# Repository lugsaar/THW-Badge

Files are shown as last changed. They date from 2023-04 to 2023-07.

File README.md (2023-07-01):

# THW-Badge

 [][cc-by-nc-sa]

## Images 

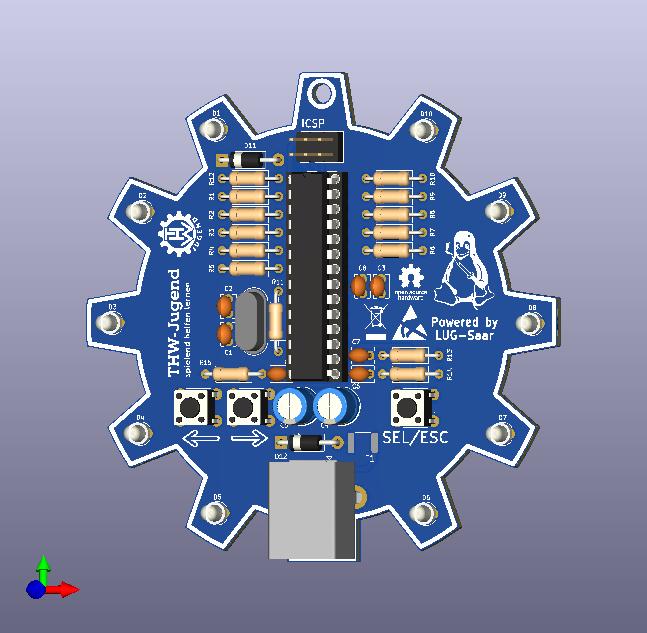
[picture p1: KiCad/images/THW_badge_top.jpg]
top

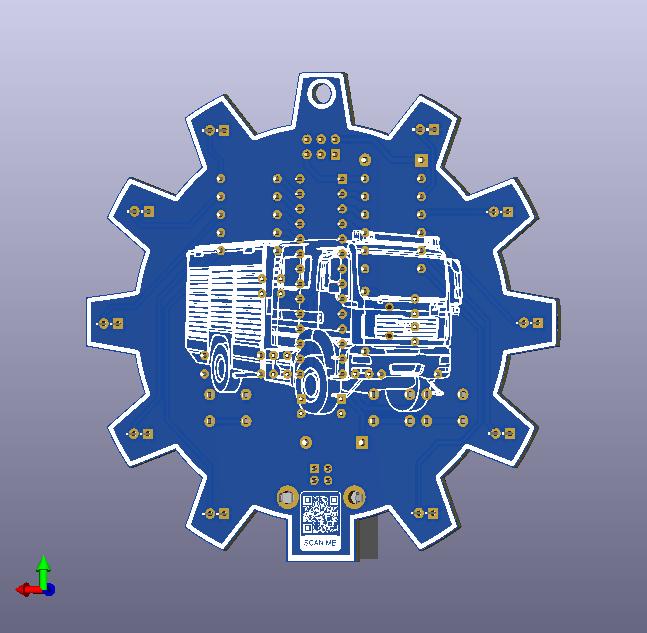
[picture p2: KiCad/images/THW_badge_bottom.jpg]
bottom

## License 

This work is licensed under a
[Creative Commons Attribution-NonCommercial-ShareAlike 4.0 International License][cc-by-nc-sa].

[][cc-by-nc-sa]

[cc-by-nc-sa]: http://creativecommons.org/licenses/by-nc-sa/4.0/
[cc-by-nc-sa-image]: https://licensebuttons.net/l/by-nc-sa/4.0/88x31.png
[cc-by-nc-sa-shield]: https://img.shields.io/badge/License-CC%20BY--NC--SA%204.0-lightgrey.svg

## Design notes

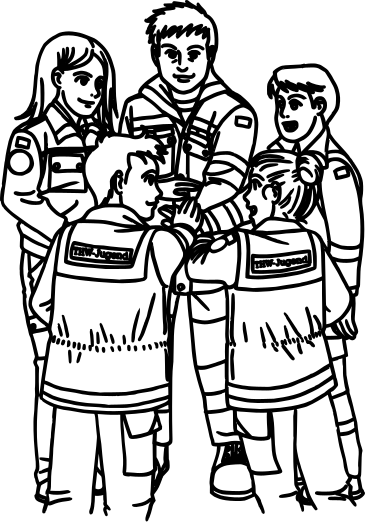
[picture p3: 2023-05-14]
KiCad/graphics/THW_Jugend_Personenkreis_Trace.jpg.png

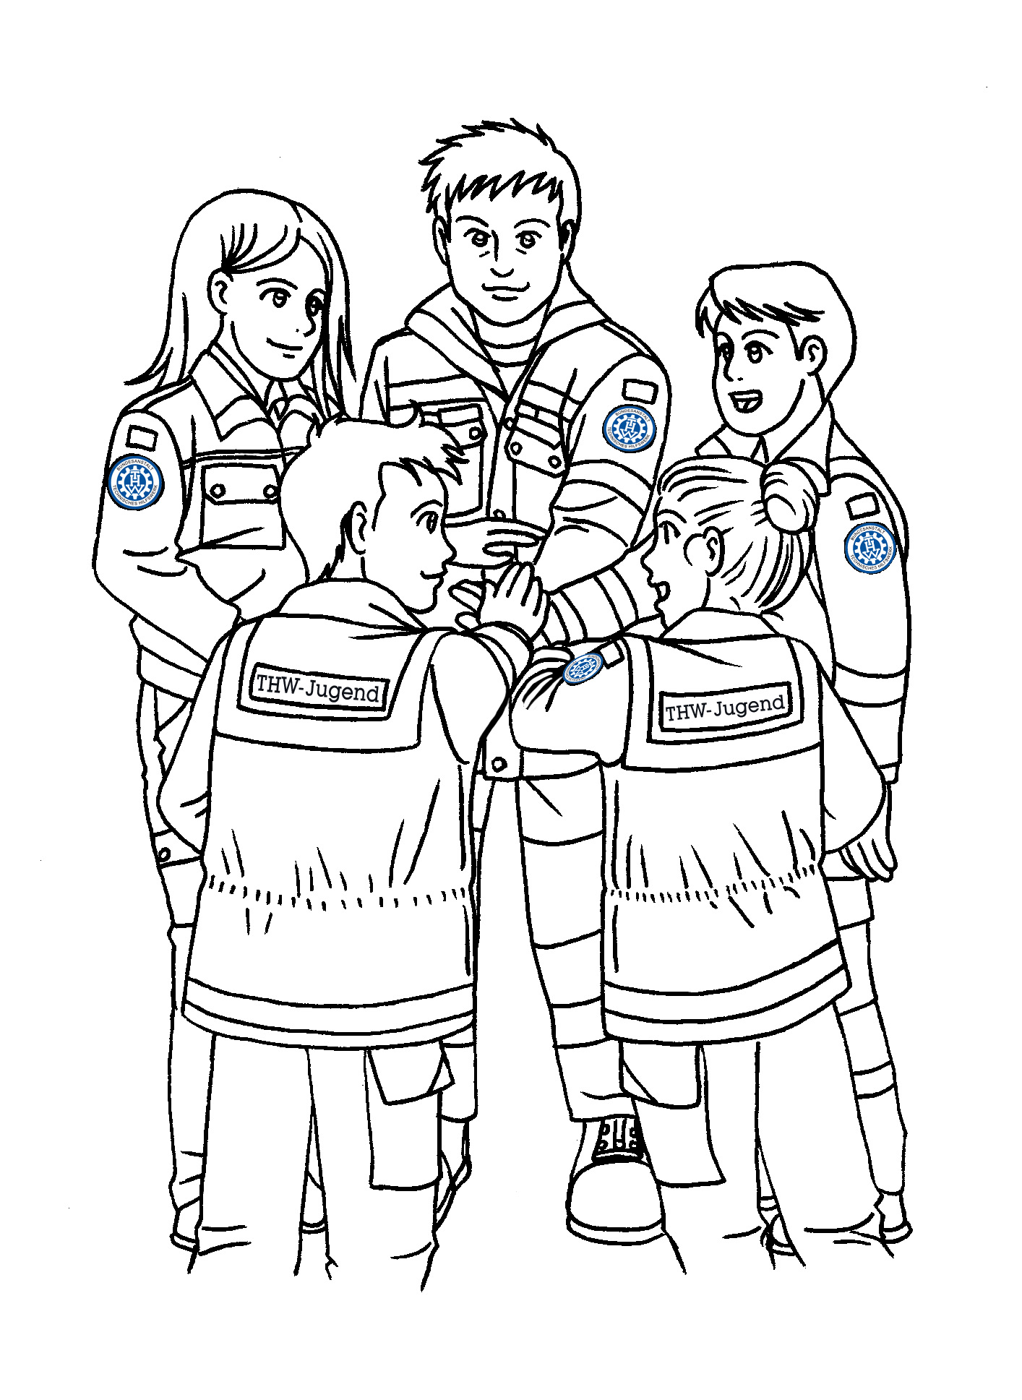
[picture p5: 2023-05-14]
KiCad/graphics/THW_Jugend_Personenkreis.jpg

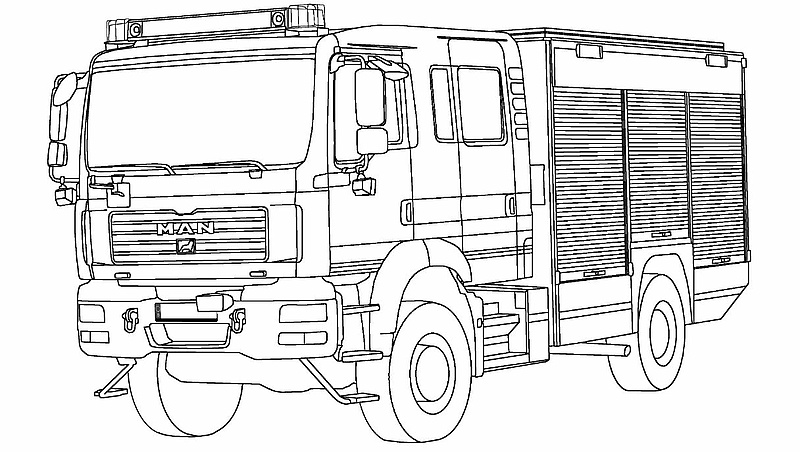
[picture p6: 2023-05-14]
KiCad/graphics/THW_GKW.jpg

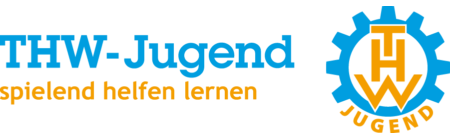
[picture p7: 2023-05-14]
KiCad/graphics/THW-Jugend_Schrift-lbox-450x140-trans.png

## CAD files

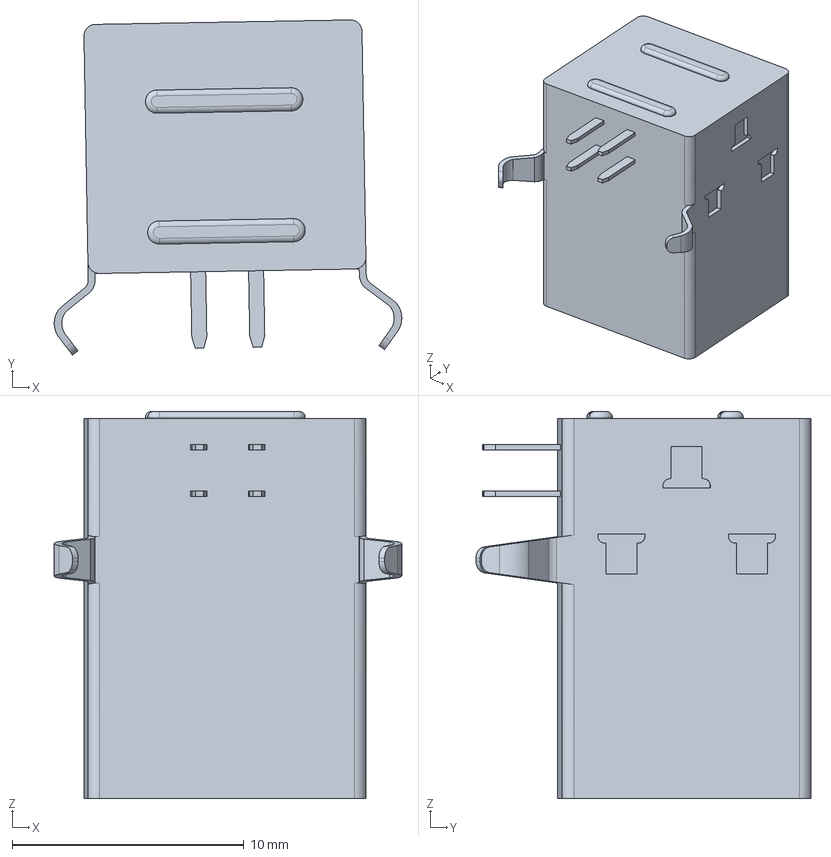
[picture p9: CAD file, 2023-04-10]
KiCad/3D_Models/USB_B_Lumberg_2411_02_Horizontal.stp
15.0 x 14.5 x 16.7 mm

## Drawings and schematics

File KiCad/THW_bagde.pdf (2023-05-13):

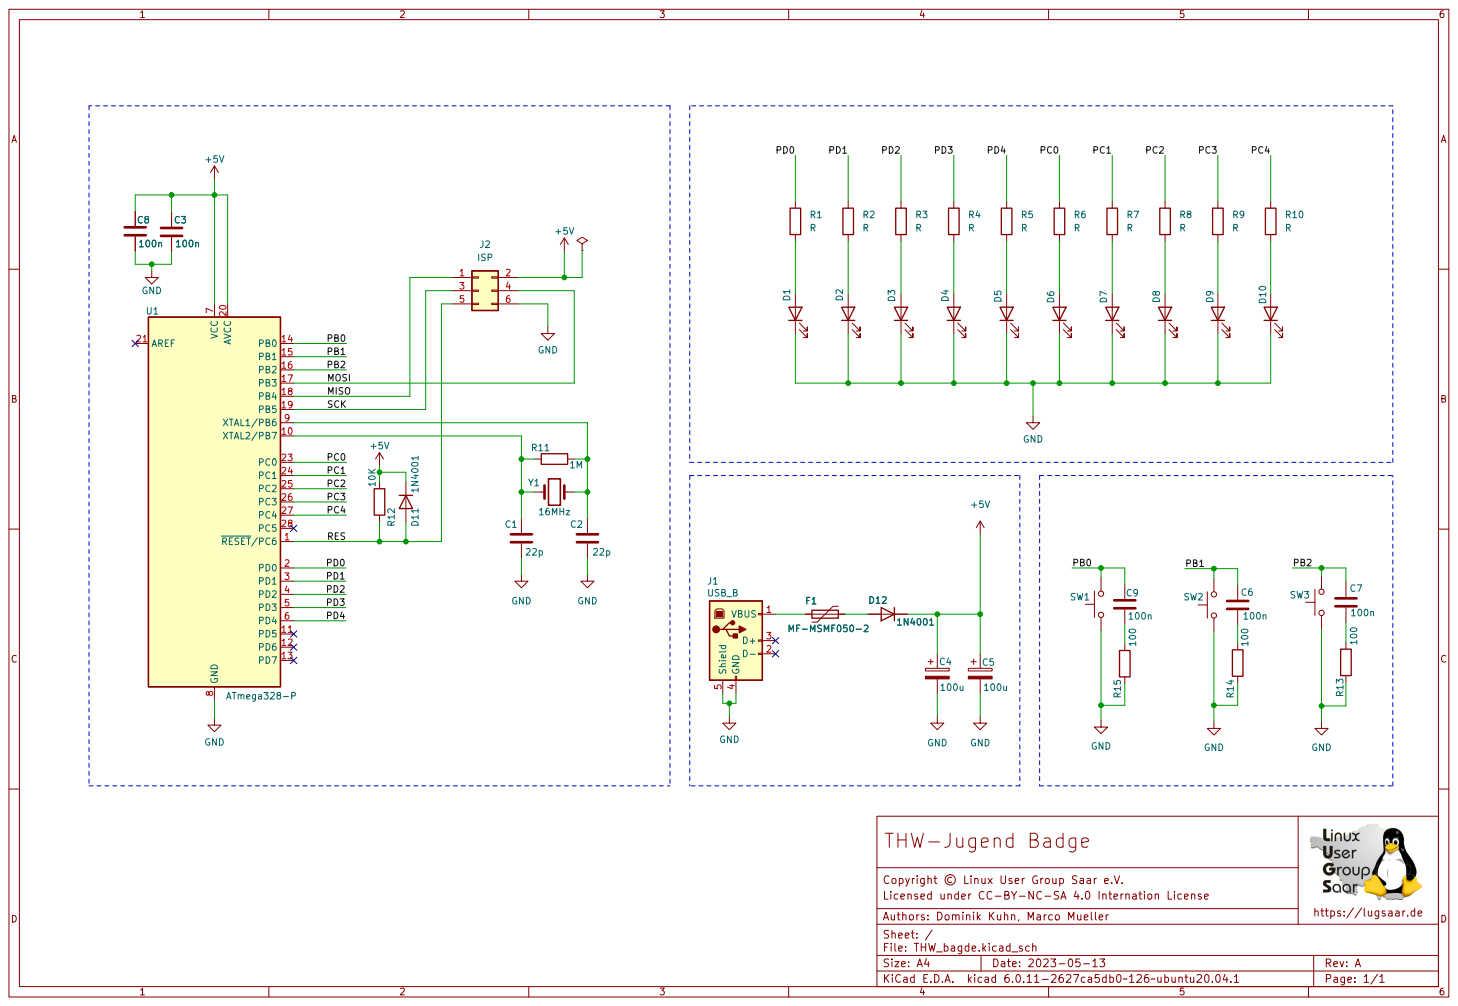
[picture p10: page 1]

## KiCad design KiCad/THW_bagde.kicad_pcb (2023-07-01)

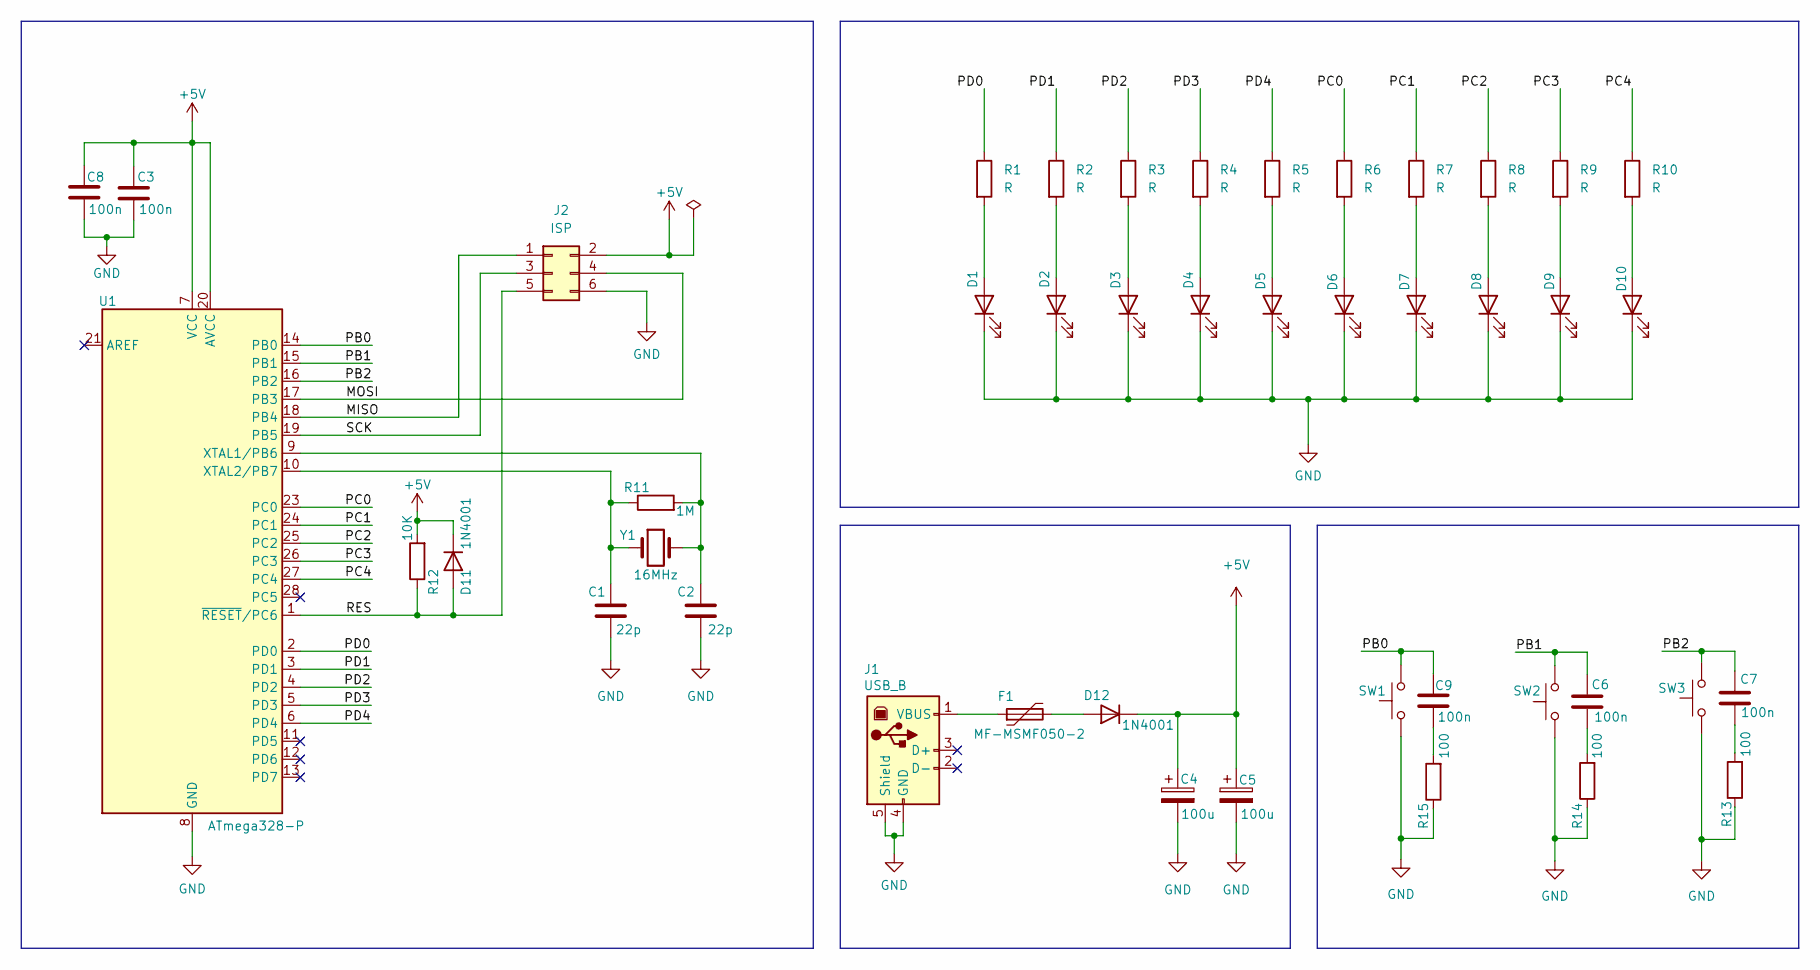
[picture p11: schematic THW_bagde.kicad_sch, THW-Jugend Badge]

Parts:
C1, C2: 22p; C_Disc_D3.8mm_W2.6mm_P2.50mm
C3, C6, C7, C8, C9: 100n; C_Disc_D3.8mm_W2.6mm_P2.50mm
C4, C5: 100u; CP_Radial_D6.3mm_P2.50mm
D1, D2, D3, D4, D5, D6, D7, D8, D9, D10: LED; LED_D3.0mm_Clear
D11, D12: 1N4001; D_DO-41_SOD81_P10.16mm_Horizontal
F1: MF-MSMF050-2; Fuse_1812_4532Metric
J1: USB_B; USB_B_Lumberg_2411_02_Horizontal
J2: ISP; PinHeader_2x03_P2.54mm_Vertical
R1, R2, R3, R4, R5, R6, R7, R8, R9, R10: R; R_Axial_DIN0207_L6.3mm_D2.5mm_P10.16mm_Horizontal
R11: 1M; R_Axial_DIN0207_L6.3mm_D2.5mm_P10.16mm_Horizontal
R12: 10K; R_Axial_DIN0207_L6.3mm_D2.5mm_P10.16mm_Horizontal
R13, R14, R15: 100; R_Axial_DIN0207_L6.3mm_D2.5mm_P10.16mm_Horizontal
SW1, SW2, SW3: SW_Push; SW_PUSH_6mm
U1: ATmega328-P; DIP-28_W7.62mm
Y1: 16MHz; Crystal_HC49-4H_Vertical

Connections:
+5V: C3.1, C4.1, C5.1, C8.1, D11.1 (K), D12.1 (K), J2.2, R12.2, U1.7 (VCC), U1.20 (AVCC)
/MISO: J2.1, U1.18 (PB4)
/MOSI: J2.4, U1.17 (PB3)
/PB0: C9.1, SW1.2, U1.14 (PB0)
/PB1: C6.1, SW2.2, U1.15 (PB1)
/PB2: C7.1, SW3.2, U1.16 (PB2)
/PC0: R6.1, U1.23 (PC0)
/PC1: R7.1, U1.24 (PC1)
/PC2: R8.1, U1.25 (PC2)
/PC3: R9.1, U1.26 (PC3)
/PC4: R10.1, U1.27 (PC4)
/PD0: R1.1, U1.2 (PD0)
/PD1: R2.1, U1.3 (PD1)
/PD2: R3.1, U1.4 (PD2)
/PD3: R4.1, U1.5 (PD3)
/PD4: R5.1, U1.6 (PD4)
/RES: D11.2 (A), J2.5, R12.1, U1.1 (~RESET/PC6)
/SCK: J2.3, U1.19 (PB5)
GND: C1.2, C2.2, C3.2, C4.2, C5.2, C8.2, D1.1 (K), D2.1 (K), D3.1 (K), D4.1 (K), D5.1 (K), D6.1 (K), D7.1 (K), D8.1 (K), D9.1 (K), D10.1 (K), J1.4 (GND), J1.5 (Shield), J2.6, R13.1, R14.1, R15.1, SW1.1, SW2.1, SW3.1, U1.8 (GND), U1.22 (GND)
unnamed: C1.1, R11.1, U1.10 (XTAL2/PB7), Y1.1
unnamed: C2.1, R11.2, U1.9 (XTAL1/PB6), Y1.2
unnamed: C7.2, R13.2
unnamed: C9.2, R15.2
unnamed: D1.2 (A), R1.2
unnamed: D2.2 (A), R2.2
unnamed: D3.2 (A), R3.2
unnamed: D4.2 (A), R4.2
unnamed: D5.2 (A), R5.2
unnamed: D6.2 (A), R6.2
unnamed: D7.2 (A), R7.2
unnamed: D8.2 (A), R8.2
unnamed: D9.2 (A), R9.2
unnamed: D10.2 (A), R10.2
unnamed: D12.2 (A), F1.2
unnamed: F1.1, J1.1 (VBUS)
unnamed: C6.2, R14.2

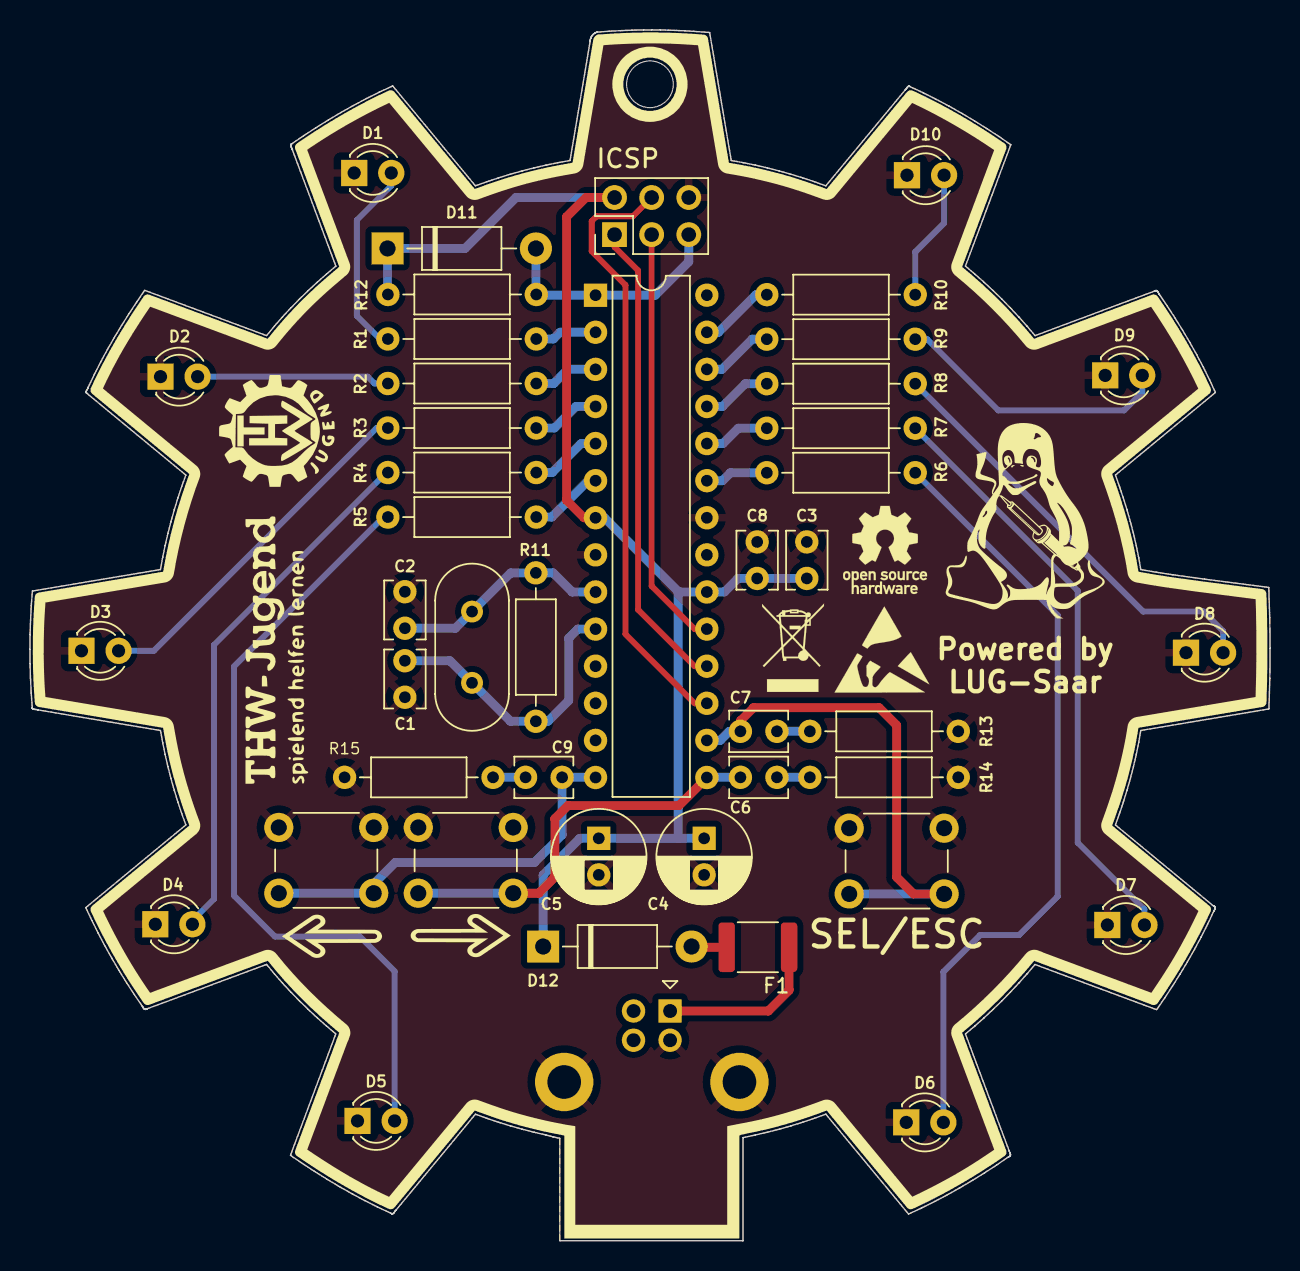
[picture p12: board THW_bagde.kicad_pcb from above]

Board: 2 copper layers, 84.9 x 82.9 mm, 44 parts (0 on the bottom side), 36 nets.

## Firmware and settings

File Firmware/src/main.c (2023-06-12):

#include "thw-badge.h"

volatile uint8_t AppNumber;
volatile uint8_t Stop;
volatile uint16_t LedCycle;
volatile uint8_t Buttons;

FuncPntr Application[] = {
    APPLICATIONS};

FuncPntr AppTimerInterrupt[] = {
    APPTIMERS};

FuncPntrBtn AppButtonInterrupt[] = {
    APPBUTTONS};

// volatile unsigned long sleep_time = 0x3FFu;

int main(void)
{

  cli(); // stop all interrupts

  initPorts();
  initPowersave();
  initButtons();

  // //START TIMER SETUP
  // //TIMER SETUP for highly preceise timed measurements
  // // turn on CTC mode
  // TCCR1A = 0;// set entire TCCR1A register to 0
  // TCCR1B = 0;// same for TCCR1B
  // TCCR1B |= (1 << WGM12);
  // // Set prescaler to 8 --> CLK / 8 = 1 MHz
  // TCCR1B |= (1 << CS11); // | (1 << CS10);

  // //initialize counter value to 0;
  // TCNT1  = 0;

  // // set timer count for 1KHz increments
  // OCR1A = 1000 - 1;

  // // enable timer compare interrupt
  // TIMSK1 |= (1 << OCIE1A);

  sei();

  // Start Launcher in sleepmode
  Stop = 0;
  Application[0]();
  // App_Wheel();

  return 0;
}

void initPorts(void)
{

  // Set Pin 0 - 4 of PORTC and PORTD as output.
  DDRC |= 0x1Fu;
  DDRD |= 0x1Fu;

  // Enable pull-ups on button input pins
  PORTB |= (1 << PORTB0) | (1 << PORTB1) | (1 << PORTB2);
}

void initPowersave(void) {
  //Disable Universal-Serial-Interface and AD-Converter
	PRR |= (1 << PRUSART0) | (1 << PRADC);
  //Select sleepmode
	set_sleep_mode(SLEEP_MODE_PWR_DOWN);
  sleep_enable();
  return;
}




void initButtons(void)
{
  // Set Pin Change Interrupt for button input pins
  PCICR |= (1 << PCIE0);
  PCMSK0 |= (1 << PCINT0) | (1 << PCINT1) | (1 << PCINT2);
}

void initCycleTimer(uint8_t _Speed)
{
  //_Speed 0 means all LEDs permanent
  if (_Speed == 0)
  {
    LedCycle = 0x3ff;
    return;
  }
  TCCR0A = 0;// set entire TCCR0A register to 0
  TCCR0B = 0;// same for TCCR0B
  // CTC mode
  TCCR0A |= (1 << WGM01);
  // CLK / 64
  TCCR0B |= (1 << CS01) | (1 << CS00);
  // Decrement counter to avoid missing interrupt
  if (TCNT0 > OCR0A)
  {
    TCNT0 = OCR0A - 1;
  }
  // Timer0 Output Compare A Match Interrupt
  OCR0A = _Speed;
  TIMSK0 |= (1 << OCIE0A);
  return;
}

void initAppTimer(uint16_t _Speed)
{
  TCCR1A = 0;// set entire TCCR1A register to 0
  TCCR1B = 0;// same for TCCR1B
  // CTC mode, CLK / 64
  TCCR1B |= (1 << WGM12);
  TCCR1B |= (1 << CS11) | (1 << CS10);
  // Decrement counter to avoid missing interrupt
  if (TCNT1 > OCR1A)
  {
    TCNT1 = OCR1A - 1;
  }
  // Timer1 Output Compare A Match Interrupt
  OCR1A = _Speed;
  TIMSK1 |= (1 << OCIE1A);
  return;
}

void activateLeds(uint16_t _Leds)
{
  // PORTC = (0x1F & _Leds);
  PORTC = 0x1Fu &  (LedCycle & _Leds);
  PORTD = 0x1Fu & ((LedCycle & _Leds) >> 5);
  return;
}

void debounceButtons(volatile uint8_t *_port, uint8_t _mask)
{
  uint8_t port_buffer;
  uint8_t debounce_buffer;
  for (debounce_buffer = 0; debounce_buffer != 0xff;)
  {
    debounce_buffer <<= 1;
    port_buffer = *_port;
    _delay_us(15);
    if ((*_port & _mask) == (port_buffer & _mask))
    {
      debounce_buffer |= 0x01;
    }
  }
  return;
}


ISR(TIMER0_COMPA_vect)
{
  cli();
  LedCycle <<= 1;
  if (LedCycle == 0)
  {
    LedCycle = 1;
  }
  sei();
  return;
}

ISR(TIMER1_COMPA_vect)
{
  cli();
  AppTimerInterrupt[AppNumber]();
  // TimerInt_Wheel();
  sei();
  return;
}

ISR(PCINT0_vect)
{
  // Wake up
  cli();
  debounceButtons(&PINB, (1 << PB0) | (1 << PB1) | (1 << PB2));
  if (!(PINB & (1 << PB0)))
  {
    Buttons |= (1 << BUTTON1);
  }
  if (!(PINB & (1 << PB1)))
  {
    Buttons |= (1 << BUTTON2);
  }
  if (!(PINB & (1 << PB2)))
  {
    Buttons |= (1 << BUTTON3);
  }
  AppButtonInterrupt[AppNumber](Buttons);
  Buttons = 0;
  sei();
  return;
}

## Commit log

2023-04-10 place some parts to see dimension of badge
    [THW_bagde.kicad_pcb, THW_bagde.kicad_sch, USB_B_Lumberg_2411_02_Horizontal.stp]
2023-04-23 adding lugsaar worksheet file
    [THW_bagde.kicad_pcb, THW_bagde.kicad_sch]
2023-04-23 LED placement
    [THW_bagde.kicad_pcb, THW_bagde.kicad_sch]
2023-04-27 ICSP-Header added
    [THW_bagde.kicad_pcb, THW_bagde.kicad_sch]
2023-05-01 adding firmware for tests
    [THW_bagde.kicad_pcb, THW_bagde.kicad_sch]
2023-05-02 fixing some silkscreen issues and adding image to README file
    [THW_bagde.kicad_pcb, THW_bagde.kicad_sch]
2023-05-03 switching to plain avr lib instead arduino framework
    [THW_bagde.kicad_sch]
2023-05-06 first tests with tks-badge firmware
    [THW_bagde.kicad_pcb, THW_bagde.kicad_sch]
2023-05-06 fixing pin mapping
    [THW_bagde.kicad_pcb, THW_bagde.kicad_sch]
2023-05-13 Changing user button circuit. Routing first components. Resize LUG logo in Drawing sheet.
    [THW_bagde.kicad_pcb, THW_bagde.kicad_sch]
2023-05-14 adding importent symbols
    [THW_bagde.kicad_pcb]
2023-05-25 routing LEDs
    [THW_bagde.kicad_pcb]
2023-05-26 adding GKW graphis to B.Silkscreen
    [THW_bagde.kicad_pcb]
2023-05-31 Adding Rendering of bottom and adding QR to GitHub Repo.
    [THW_bagde.kicad_pcb]
2023-07-01 first order
    [THW_bagde-CuBottom.gbr, THW_bagde-CuTop.gbr, THW_bagde-EdgeCuts.gbr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]

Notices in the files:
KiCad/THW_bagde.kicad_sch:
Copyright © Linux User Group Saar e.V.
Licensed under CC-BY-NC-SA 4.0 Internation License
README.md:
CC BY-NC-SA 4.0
